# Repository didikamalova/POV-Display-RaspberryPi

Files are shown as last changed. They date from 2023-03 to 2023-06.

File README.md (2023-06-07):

<h1> :earth_asia:  Persistence of Vision (POV) Display  :earth_asia: </h1>

<h1> Team Members </h1>
- Didi Kamalova <br>
- Naomi Mo <br>
- Aanya Tashfeen <br>

<h1> Project Description </h1>
We created a spherical persistence of vision (POV) LED Display that works by spinning a circular array of LEDs and relies on our eyes' natural “refresh rates” to create the illusion of a solid image on a sphere. Equipped with an LED strip, a hall sensor, 3 battery packs and framed in a desk fan, it creates patterns upon reacting to magnets spaced out across the circular base.

<h1> References </h1>
- POV Globe <a href="https://www.youtube.com/watch?v=E4yqSw38R_Q&t=178s](https://youtu.be/E4yqSw38R_Q">Video</a> and <a href="https://github.com/rottaca/PovGlobe.git">GitHub Repository</a> <br>
- SPI module code by <a href="https://github.com/cs107e/cs107e.github.io/blob/25d6d0b08f8accd1bdcaf4e400c9574a3f2c0dcf/lectures/Sensors/code/arducam/spi.c">Arducam</a> <br>
- Pat's hall effect sensor code <br>

<h1> Self-Evaluation </h1>
<p> We created a fully functioning prototype of a spherical LED Display that allows for free spinning, coded an LED strip driver, integrated hall sensor interrupts and successfully projected a soccerball pattern on the sphere. While we have not been able to project a spherical image of the globe as was initally planned, we were able to complete all other goals that we have set for this project! </p>

<p align="center">
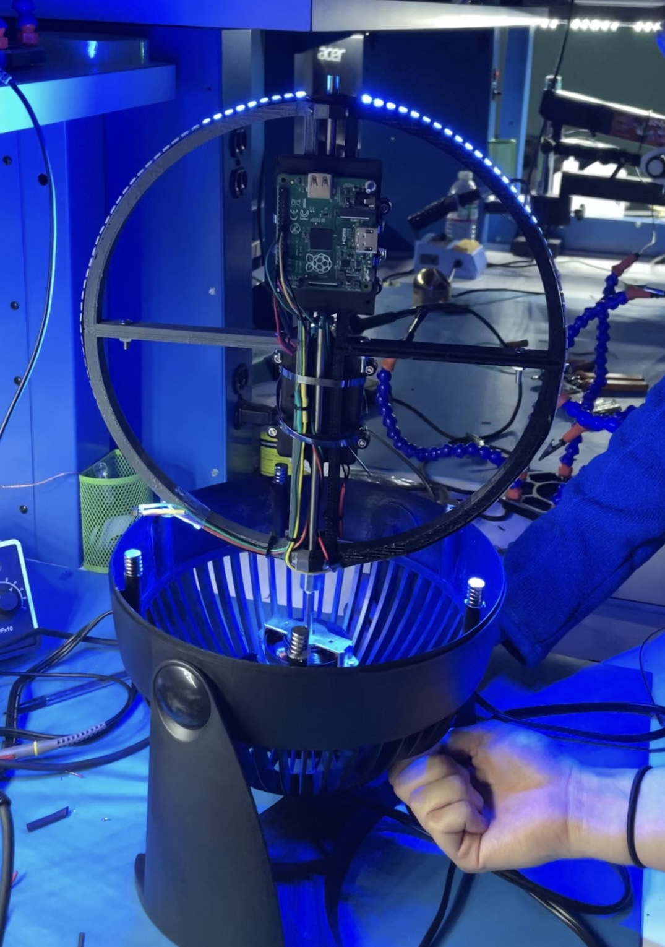
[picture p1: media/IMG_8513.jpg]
  
</p>
<p align="center">
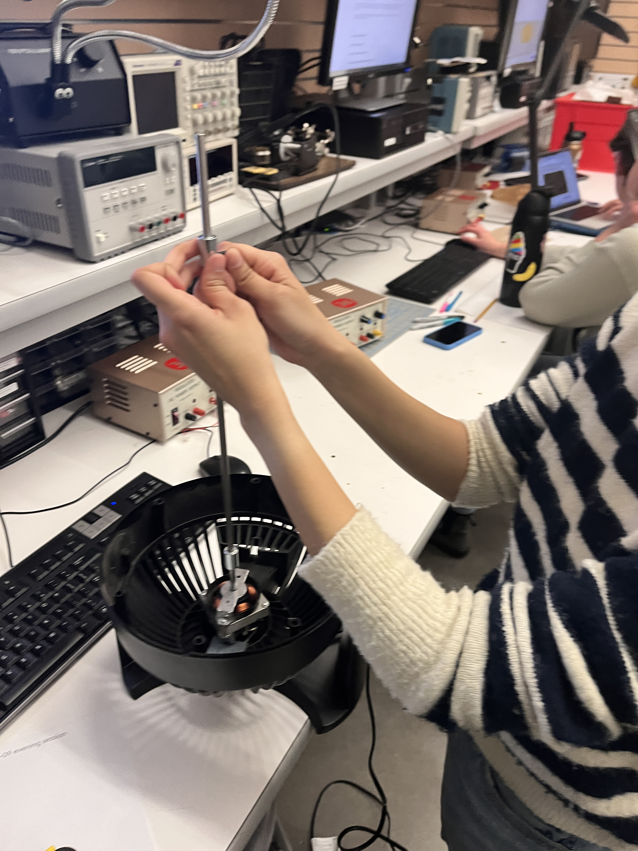
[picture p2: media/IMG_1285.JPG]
  
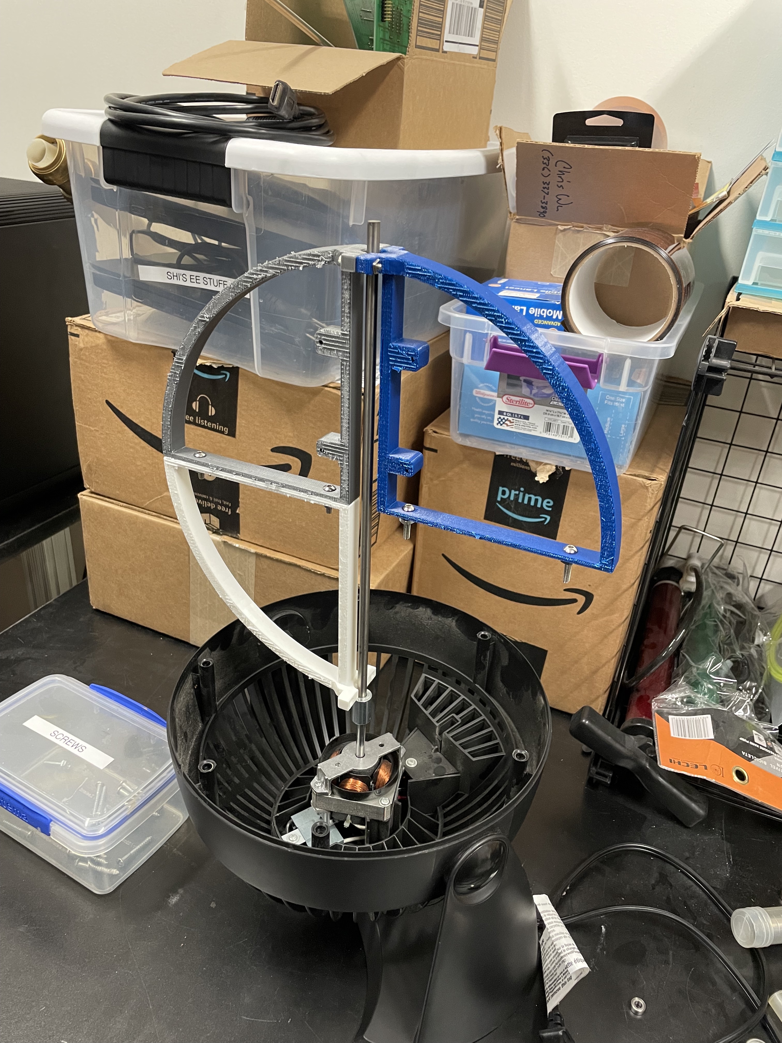
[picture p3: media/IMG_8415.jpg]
  
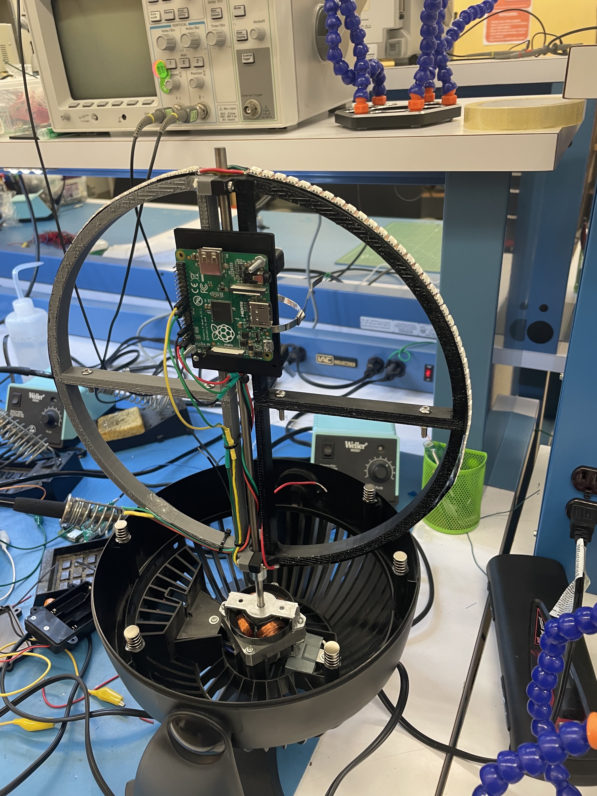
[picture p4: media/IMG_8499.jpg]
  
</p>

More images provided in the "media" folder!

NOTE ABOUT CODE ORGANIZATION:
The simple code that we ran during demo day is under main, but more intricate implementations involving round trip time and displaying image arrays (the globe, soccer ball, and checkerboard) are under globe.c and RTTmeasure.c. We unfortunately did not get these to be fully optimized and integrated by the end of the project deadline, although we made the soccer ball display operational after our demonstration.

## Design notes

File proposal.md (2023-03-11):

## Title:
Persistence of Vision (POV) Display

## Team Members:
Naomi Mo
Didi Kamalova
Aanya Tashfeen

## Project Description:
We want to create a spherical persistence of vision (POV) LED Display. 

Our goal is to create a fully functinoning LED Display that works by spinning a circular array of LEDs and relies on our eyes' natural “refresh
rates” to create the illusion of a solid image on a sphere.

We want to be able to display fun patterns (disco ball, for example) on it. If that works, we want to try encoding an image of the globe on our display and/or adding peripherals to it.

## Hardware & Budget:
Required hardware:
- x1 A3134 Hall Effect Sensor - Pat
- x8 Neodymium Magnets - Pat
- x2 AdaFruit DotStar LED strip 144 LED/m 0.5m - lab64
- x1 3AA Battery Pack - lab64
- x10 M4, M5 bolts & nuts - lab64/room 36
- x5 3D Printed Parts - lab64
- x1 ~200x200x20mm Steel/Wood Base Plate - lab64/room 36 wood scraps
- x1 2000-3000RPM DC Motor (4mm) - Stanford Robotics Lab/Aanya's Fan
- x1 6.3mm aluminum/steel rod - Room 36
<<<<<<< Updated upstream
- x1 (^) DC Motor Adapter (5mm to 6mm) - Stanford Robotics Lab
- x1 Ball Bearing - Stanford Robotics Lab/Room 36
=======
- x1 (^) DC Motor Adapter - Stanford Robotics Lab
- x1 Ball Bearing - Room 36
>>>>>>> Stashed changes
- x1 Power Supply (for testing purposes) - lab64

(^) - items we're still searching for and may need to purchase elsewhere.

Rough Budget: $50-60 for components we won't be able to find.

## Tasks & Member Responsibilities:
Our project will be divided into the following categories:
Software: graphics module (gl_draw() functions), hall sensor driver, led driver, implementing interrupts throughout
Electrical: circuit schematics, power management, soldering.
Mechanical: ring, frame, motor, cable management, assembly.

Division of tasks (not final):

Aanya: mechanical assembly, math for graphics

Didi: led setup, circuits, hardware sourcing, mechanical assembly

Naomi: hall sensors setup, mechanical assembly

## Schedule & Midpoint Milestones:
By the end of the upcoming weekend, we want our entire mechanical assembly in place. By the end of the following weekend, we want a working sphere 
with a functional LED display. 

## Resources Needed & Issues:
Our possible concerns include mechanical/electrical assembly problems that we may run into, such as rotating wires getting tangled up, poor electrical power trasmission, lack of frame stability, extra motor vibrations  and lack of battery capacity.

In the event we encounter issues with the 3D display, we plan on working on a 2D LED display instead.

Resources: POV globe video and github repo: https://www.youtube.com/watch?v=E4yqSw38R_Q&t=178s
		   Julie's LED strip driver code and Pat's hall effect sensor code
		   Math libraries from cs 107e repo

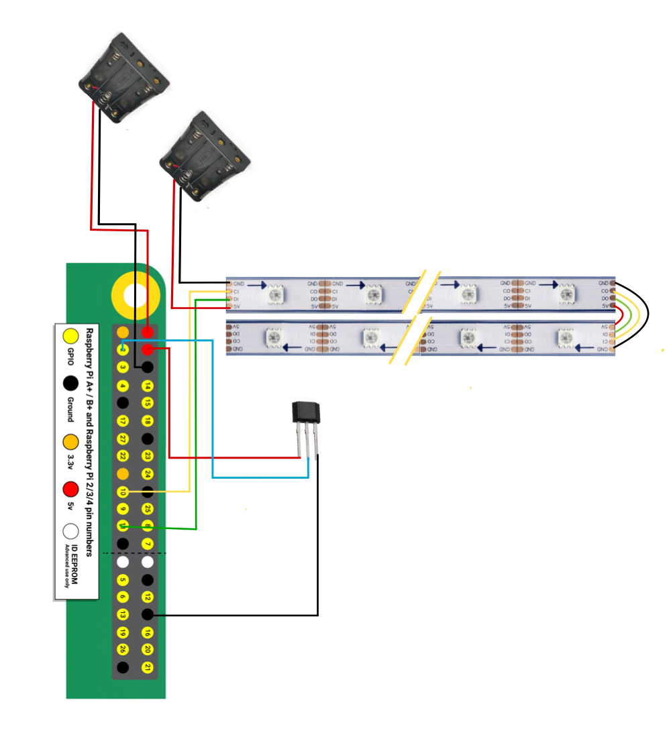
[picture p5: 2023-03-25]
schematics/circuit.jpeg

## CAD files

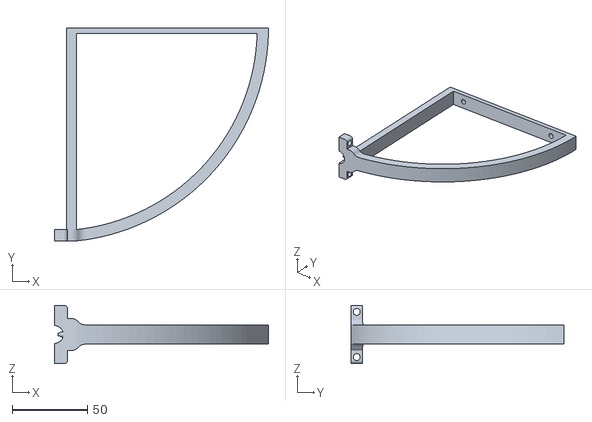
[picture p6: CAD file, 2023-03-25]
stl_files/rotor_bottom_right 1.5 mm extrusion.stl
141.8 x 141.1 x 38.5

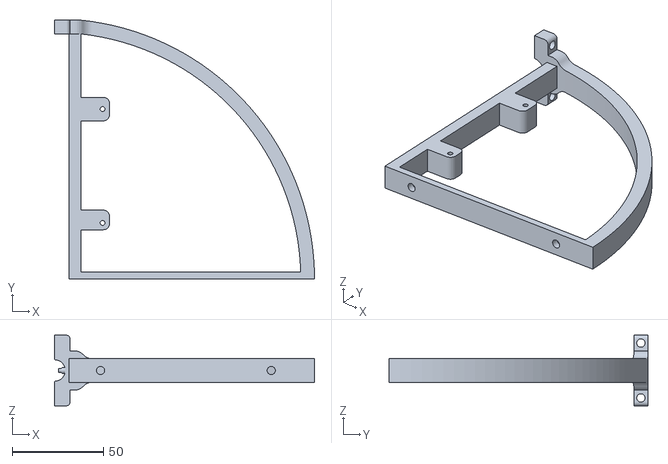
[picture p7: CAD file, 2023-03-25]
stl_files/rotor_top_right 1.5 mm extrusion.stl
142.1 x 141.4 x 38.6

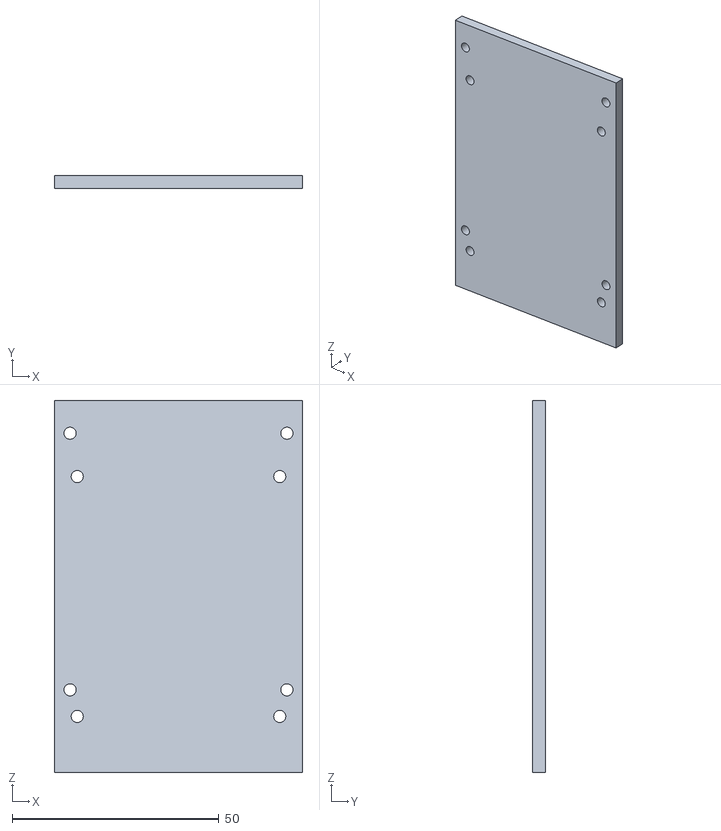
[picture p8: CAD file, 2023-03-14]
stl_files/mount for pi v2.stl
60.0 x 3.15 x 90.0

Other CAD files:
stl_files/rotor_top_left 1.5 extrusion.stl
stl_files/rotor_bottom_left 1.5 mm extrusion.stl
stl_files/mount for battery v2.stl

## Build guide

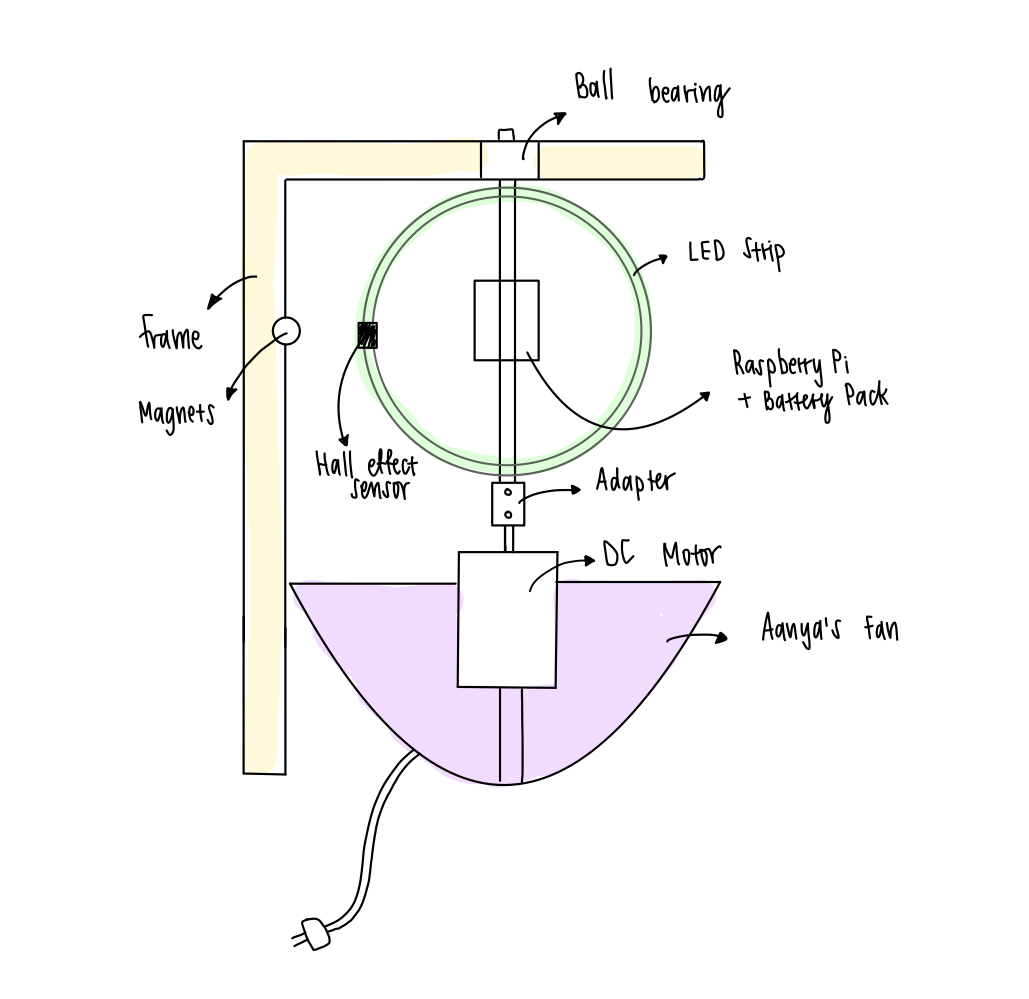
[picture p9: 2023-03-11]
schematics/setup.jpeg

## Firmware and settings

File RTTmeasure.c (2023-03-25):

/* Filename: RTTmeasure.c
 * This file contains the code for calculating the round trip time for the hall sensor
 * mounted on the spinning circular frame. The code starts reading the time as soon as 
 * RTT is initialized, so there must be a delay in the main function to account for 
 * the motor speeding up, prior to initialization.
 * 
 * The code calculates the average round trip time using the 6 magnets and then works out
 * the average time per column. The code then keeps track of the changing column numbers
 * and standardizes one column above the magnet to ensure consistency among the projected
 * images, which is why we used 6 magnets. The magnets were not equi-distant apart, so we had
 * to keep track of measured interval times. The column numbers are used to know what 'pixels'
 * each LED should be driven to in that position on the globe.
 *
 * Typically, frames per second is defined by the number of rotations of the motor per second (RPM/60).
 * This code computes columns 0 to HORIZONTAL_RESOLUTION for every frame while the motor is on, if find_column
 * called in an infinite while loop.
 *
 * Citation: Andreas Rottach, github username: rottaca
 * Link: https://github.com/rottaca/PovGlobe/blob/master/pico_src/Renderer/RTTMeasure.hpp
 * Our implementation of the RTT code was based on this approach. However, our code was written from scratch after
 * looking over this code and was designed to interface with the way we had implemented hall sensor interrupts. Our
 * magnets were also not equal distant apart, but his code assumes that they were, so our code was written to discard this
 * assumption. This involved keeping track of a lot more variables and data.
 */
#include "hall.h"
#include "timer.h"
#include "constants.h"
#include "printf.h"
#include "string.h"
#include "gpio.h"
#include "apa102.h"
#include "uart.h"

static volatile int prev_magnet = 0;
static volatile int cur_magnet = 0;
static unsigned int measured_intervals[NUM_MAGNETS*3];
static unsigned int avg_intervals[NUM_MAGNETS];
static unsigned int col_start_in_segment[NUM_MAGNETS];
volatile unsigned int event_time = 0;
volatile unsigned int prev_time = 0;
unsigned int RTT_time = 0;
volatile unsigned int column = 0;

void find_avg_intervals(void);
void find_start_col_segment(void);

// RTT init initializes hall sensor and then calculates average RTT and column time
// based on horizontal resolution (i.e. no. of columns).
void RTT_init(void) {
	hall_init(); // hall code now initialized
	timer_init();

	memset(measured_intervals, '\0', sizeof(measured_intervals));
	memset(avg_intervals, '\0', sizeof(avg_intervals));

	find_avg_intervals();
	find_start_col_segment(); // find the starting column above each magnet

}

// updates last hall event time
void get_event_time_init(void) {
    cur_magnet = hall_read_event(); // must continuously read this somewhere in code
    // commented out code is a time buffer for when the motor turns on to allow for 
    // the motor to speed up to a constant speed
//	if (event_time == 0) {
//	    unsigned int time_start = timer_get_ticks();
//		while (timer_get_ticks() - time_start >= 5*1000*1000) {
//	        cur_magnet = hall_read_event();
//	    }
//	}
    if (cur_magnet != prev_magnet) { // detects magnet change
		prev_magnet = cur_magnet;
		event_time = timer_get_ticks();
	}
}

// wrapper function for last hall event time
unsigned int last_hall_event_time(void) {
    return event_time;
}

// This function stores measured intervals between magnets for 3 rotations
// in an array called measured_intervals.
void find_measured_intervals(void) {
		    get_event_time_init();
			// essentially wait until next hall reading
		    while (last_hall_event_time() == prev_time) {
			    get_event_time_init();
			}
			prev_time = last_hall_event_time();
    // Store time between magnet segments for 3 full rotations
    for (int i = 0; i < NUM_MAGNETS*3; i++) {
		    get_event_time_init();
		    while (last_hall_event_time() == prev_time) {
			    get_event_time_init();
			}
			// calculate interval time between magnets
			measured_intervals[i] = last_hall_event_time() - prev_time;
			prev_time = last_hall_event_time();
	}
}


// once we have the measured intervals, we no longer care about the ringbuffer
// we just want which_magnet at any given moment
void find_avg_intervals(void) {
    find_measured_intervals();
    for (int i = 0; i < NUM_MAGNETS; i++) {
		avg_intervals[i] = (measured_intervals[i] + measured_intervals[NUM_MAGNETS] + 
								measured_intervals[NUM_MAGNETS*2])/3;
	}
    for (int i = 0; i < NUM_MAGNETS; i++) {
		RTT_time += avg_intervals[i];
	}
}

const unsigned int time_per_column(void) {
    return RTT_time / HORIZONTAL_RESOLUTION;
}

// find the start column in each segment
// this is so the column would remain consistent frame to frame
void find_start_col_segment(void) {
     col_start_in_segment[0] = 0;
     for (int i = 1; i < NUM_MAGNETS; i++) {
	      // Column start determined by time in segment divided by the time per column to get no. of columns
		  // in segment. This is the offset to be added to the previosuly calculated column start of the
		  // previous magnet.
          col_start_in_segment[i] = col_start_in_segment[i-1] + (avg_intervals[i-1] / time_per_column());
	 }
}

// time in segment we're currently in based on
// hall sensor reading.
unsigned int time_in_cur_segment(void) {
    return avg_intervals[cur_magnet - 1];
}

// This function updates event time for the last hall sensor reading, the current magnet
// and the start column we're at.
// This is to ignore the ring buffer implementation of the hall sensor interrupts.
// This is because we don't need to keep track of every interrupt, but only at the 
// very moment we decide to call this function to find the column. 
void get_imm_event_time(void) {
   cur_magnet = get_which_magnet(); // function in hall sensor code to return current magnet
   if (cur_magnet != prev_magnet) {
		event_time = timer_get_ticks();
		prev_magnet = cur_magnet;
		column = col_start_in_segment[cur_magnet - 1];
   }
}

// Find the current column we're at that we need to display
unsigned int find_column(void) {
    get_imm_event_time();
	if ((timer_get_ticks() - event_time) >= time_per_column()) {
        column = (column + 1) % HORIZONTAL_RESOLUTION; // increment column by one, once time per column passes
	}
	return column;
}

// Find opposite column to display on the LED strip on the opposite side of the circular frame
unsigned int find_opposite_column(void) {
	return (column + (HORIZONTAL_RESOLUTION/2)) % HORIZONTAL_RESOLUTION;
}

// Testing code
// Had more printf statements in code to debug too
//void main(void) {
  //  RTT_init();
//	unsigned int prev_column = -1;
//	//hall_init();
//	while (1) {
//	    //int magnet = hall_read_event();
//		//printf("%d", magnet);
//	    unsigned int fcolumn = find_column();
//		if (fcolumn != prev_column) {
//	        printf("%d\n", fcolumn);
//		    prev_column = fcolumn;
//			//uart_putchar('-');
//		}
//	}
//}
//

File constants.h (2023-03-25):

// define all important constants


#define VERTICAL_RESOLUTION 60 // no. of LEDs on each side
#define HORIZONTAL_RESOLUTION 120 // calculate this by doing math - circumference of circular frame/width of LED strip
#define CHANNELS_PER_PIXEL 4 // ABGR

#define NUM_MAGNETS 6

#define NUM_PIXELS (VERTICAL_RESOLUTION*HORIZONTAL_RESOLUTION) // size in pixels/LEDs
#define BUFFER_SIZE_PER_COLUMN (VERTICAL_RESOLUTION*CHANNELS_PER_PIXEL)
#define BUFFER_SIZE (NUM_PIXELS*CHANNELS_PER_PIXEL) // buffer size in bytes

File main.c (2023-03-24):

#include "apa102.h"
#include "spi.h"
#include "uart.h"
#include "timer.h"
#include "hall.h"

// comment out tests we don't wish to run
void main(void)
{
    uart_init();
    //hall_init(); // commented out for post-demo day testing
    apa102_init();

	// simple LED driver test
    for (int i = 0; i < 20; i++) {
        apa102_clear(BLUE);
        apa102_show();
        timer_delay_ms(300);
        apa102_clear(RED);
        apa102_show();
        timer_delay_ms(300);
        apa102_clear(GREEN);
        apa102_show();
        timer_delay_ms(300);
    }

	// simple LED driver initialization check
	apa102_clear(RED);
	apa102_show();
	timer_delay(3);

	// simple hall event -> color change test
//	int count = 0;
//	while(1) {
//		hall_read_event();
//		if (count == 0) {
//			apa102_clear(RED);
//			count++;
//		} else if (count == 1) {
//			apa102_clear(BLUE);
//			count++;
//		} else {
//			apa102_clear(GREEN);
//			count = 0;
//		}
//		apa102_show();
//	}

    uart_putchar(EOT);
}

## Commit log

2023-03-08 stl files
    [motor_mount.stl, pico_mount.stl, power_transmition_part_1.stl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]
2023-03-10 Added CS107E neopixel driver library.
2023-03-10 Added hall effect sensor code from lecture. Will test soon.
2023-03-10 Added photo of Aanya adding the central rod to her disassembled fan's motor :D
2023-03-11 Editing hall file to add interrupts.
2023-03-11 Began hall interrupts.
2023-03-11 3d printing
2023-03-11 added out stl files
    [motor_mount.stl, pico_mount.stl, power_transmition_part_1.stl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]
2023-03-11 Change hall makefile
2023-03-12 Added interrupts to the hall sensor.
2023-03-12 spi driver
2023-03-12 test led
2023-03-12 spi makefile
2023-03-13 led.c upd
2023-03-14 led strip code updates
2023-03-14 fixing spi.h
2023-03-14 hall code, separate init and read
2023-03-15 led driver code upd
2023-03-15 led test makefile
2023-03-15 columns not continuosuly printing in RTTmeasure
2023-03-15 column issue: Makefile problem? info from hall file not continuous
    [RTTmeasure.c, hall.c]
2023-03-15 Makefile error on RTTmeasure with hall
    [hall.c]
2023-03-15 apa102 driver
2023-03-16 led strip attached to the frame
2023-03-16 clutch makefile for RTT/hall
2023-03-16 moved which magnet to above interrupts init
2023-03-16 found problem in RTTmeasure
    [RTTmeasure.c]
2023-03-17 working hall sensor code
2023-03-18 Testing main - switch between RGB on hall event.
2023-03-18 Cleaned hall code.
2023-03-23 Adjusted number of LEDs
2023-03-23 testing LEDs
2023-03-23 changed magnets constants
2023-03-24 Hall code cleaned, ready for submission.
2023-03-24 Hall code cleaned and ready for submit.
2023-03-25 Citation for hall added.
2023-03-25 uptodate stl_files
    [rotor_bottom_right 0.5145 extrusion.stl, rotor_bottom_right 1.5 mm extrusion.stl, rotor_top_left 0.5145 extrusion.stl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]
2023-03-25 Added additional hall comments.
2023-03-25 schematics upd
